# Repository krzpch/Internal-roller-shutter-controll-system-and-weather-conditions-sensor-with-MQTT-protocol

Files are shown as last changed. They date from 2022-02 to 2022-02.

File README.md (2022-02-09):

# Internal-roller-shutter-controll-system-and-weather-conditions-sensor-with-MQTT-protocol

This project is a part of smart home system based on MQTT protocol for comunication.
Weather condtions sensor is battery operated. To comunicate with shutter controll it uses Bluetooth Low Energy.
Shutter controll comunicates by Wi-Fi with MQTT Broker. It also works as a gate between Broker and Weather conditions sensor.

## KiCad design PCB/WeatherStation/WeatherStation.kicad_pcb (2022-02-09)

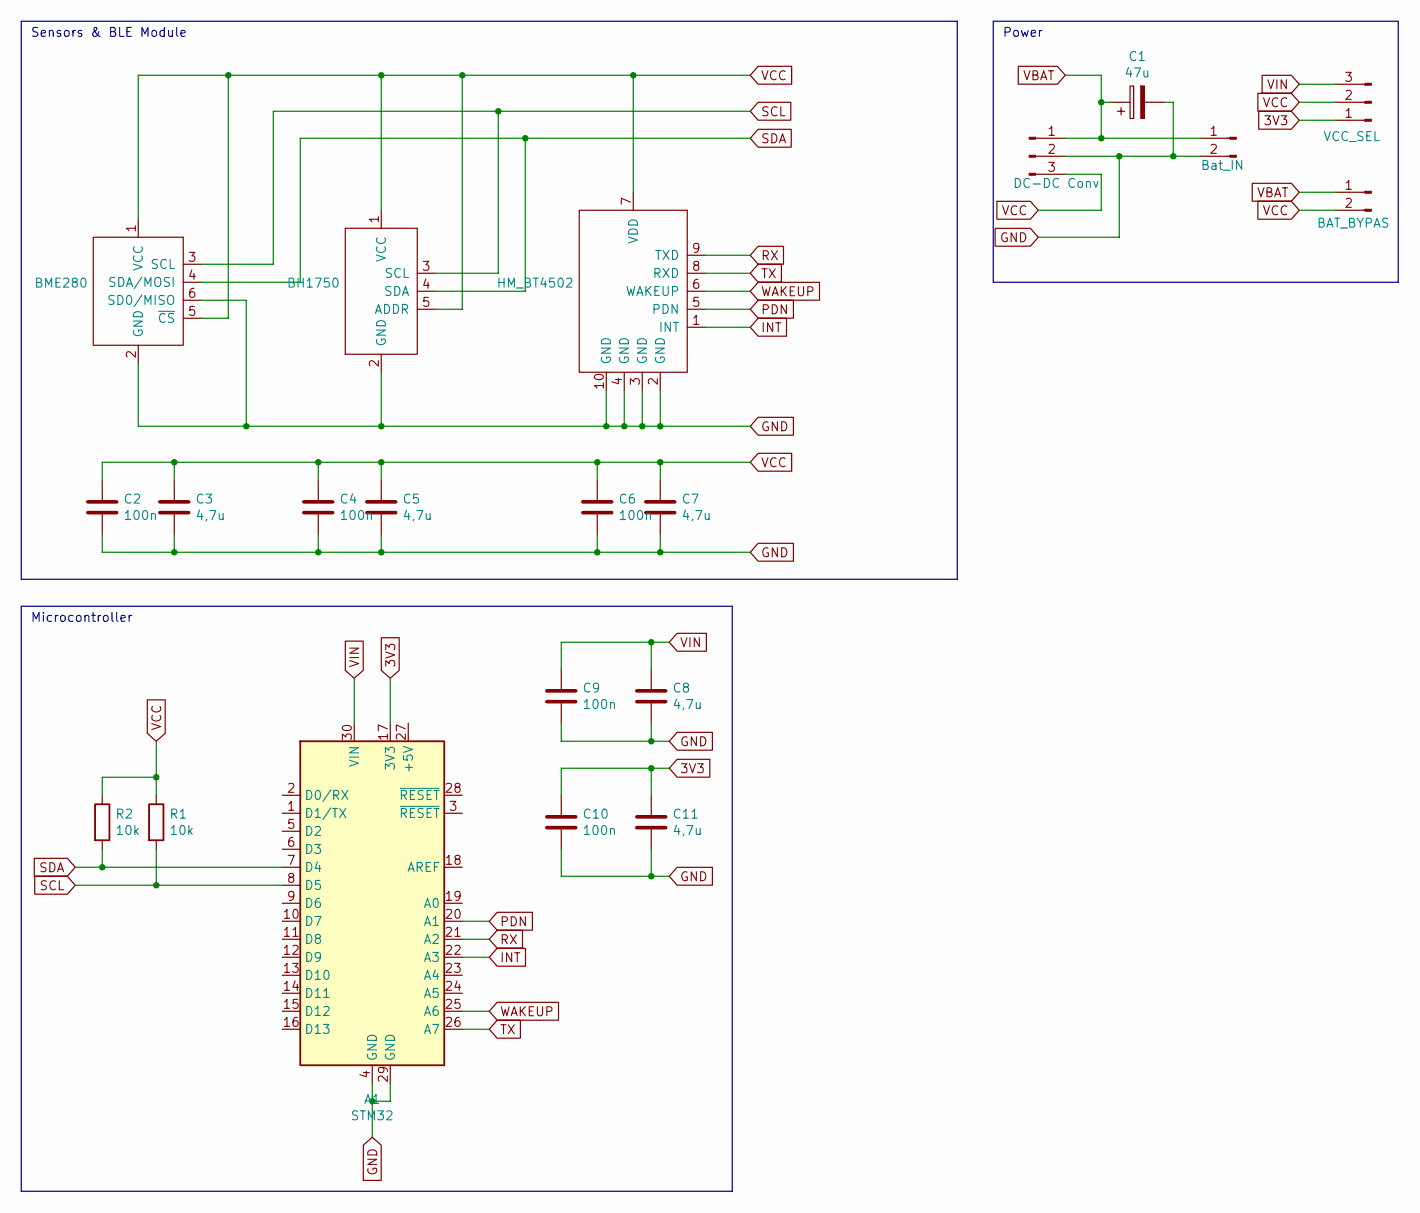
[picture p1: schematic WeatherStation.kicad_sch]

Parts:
A1: STM32; Arduino_Nano
BH1750: BH1750; PinHeader_1x05_P2.54mm_Vertical
BME280: BME280; PinHeader_1x06_P2.54mm_Vertical
C1: 47u; CP_Radial_D5.0mm_P2.00mm
C2, C4, C6, C9, C10: 100n; C_1206_3216Metric_Pad1.33x1.80mm_HandSolder
C3, C5, C7, C8, C11: 4,7u; C_1206_3216Metric_Pad1.33x1.80mm_HandSolder
HM_BT4502: HM_BT4502; HM-BT4502
J1: BAT_BYPAS; PinHeader_1x02_P2.54mm_Vertical
J2: VCC_SEL; PinHeader_1x03_P2.54mm_Vertical
J3: DC-DC Conv; PinHeader_1x03_P2.54mm_Vertical
J4: Bat_IN; PinHeader_1x02_P2.54mm_Vertical
R1, R2: 10k; R_Axial_DIN0207_L6.3mm_D2.5mm_P7.62mm_Horizontal

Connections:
3V3: A1.17 (3V3), C10.1, C11.1, J2.1
GND: A1.4 (GND), A1.29 (GND), BH1750.2 (GND), BME280.2 (GND), BME280.6 (SD0/MISO), C1.2, C2.2, C3.2, C4.2, C5.2, C6.2, C7.2, C8.2, C9.2, C10.2, C11.2, HM_BT4502.2 (GND), HM_BT4502.3 (GND), HM_BT4502.4 (GND), HM_BT4502.10 (GND), J3.2, J4.2
INT: A1.22 (A3), HM_BT4502.1 (INT)
PDN: A1.20 (A1), HM_BT4502.5 (PDN)
RX: A1.21 (A2), HM_BT4502.9 (TXD)
SCL: A1.8 (D5), BH1750.3 (SCL), BME280.3 (SCL), R1.2
SDA: A1.7 (D4), BH1750.4 (SDA), BME280.4 (SDA/MOSI), R2.2
TX: A1.26 (A7), HM_BT4502.8 (RXD)
VBAT: C1.1, J1.1, J3.1, J4.1
VCC: BH1750.1 (VCC), BH1750.5 (ADDR), BME280.1 (VCC), BME280.5 (~CS), C2.1, C3.1, C4.1, C5.1, C6.1, C7.1, HM_BT4502.7 (VDD), J1.2, J2.2, J3.3, R1.1, R2.1
VIN: A1.30 (VIN), C8.1, C9.1, J2.3
WAKEUP: A1.25 (A6), HM_BT4502.6 (WAKEUP)

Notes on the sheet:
Power
Microcontroller
Sensors & BLE Module

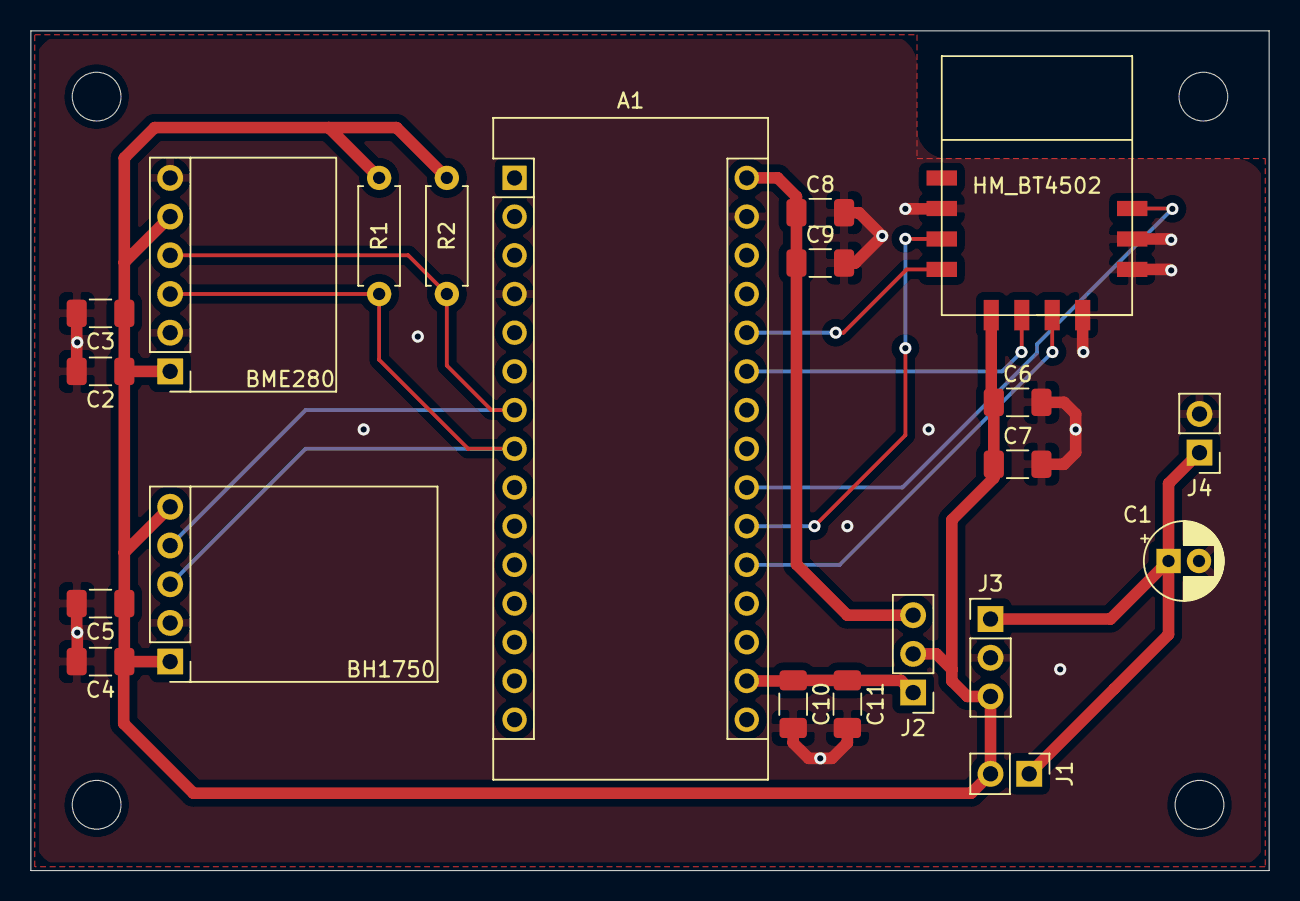
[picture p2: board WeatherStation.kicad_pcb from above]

Board: 2 copper layers, 81.3 x 55.1 mm, 21 parts (0 on the bottom side), 12 nets.

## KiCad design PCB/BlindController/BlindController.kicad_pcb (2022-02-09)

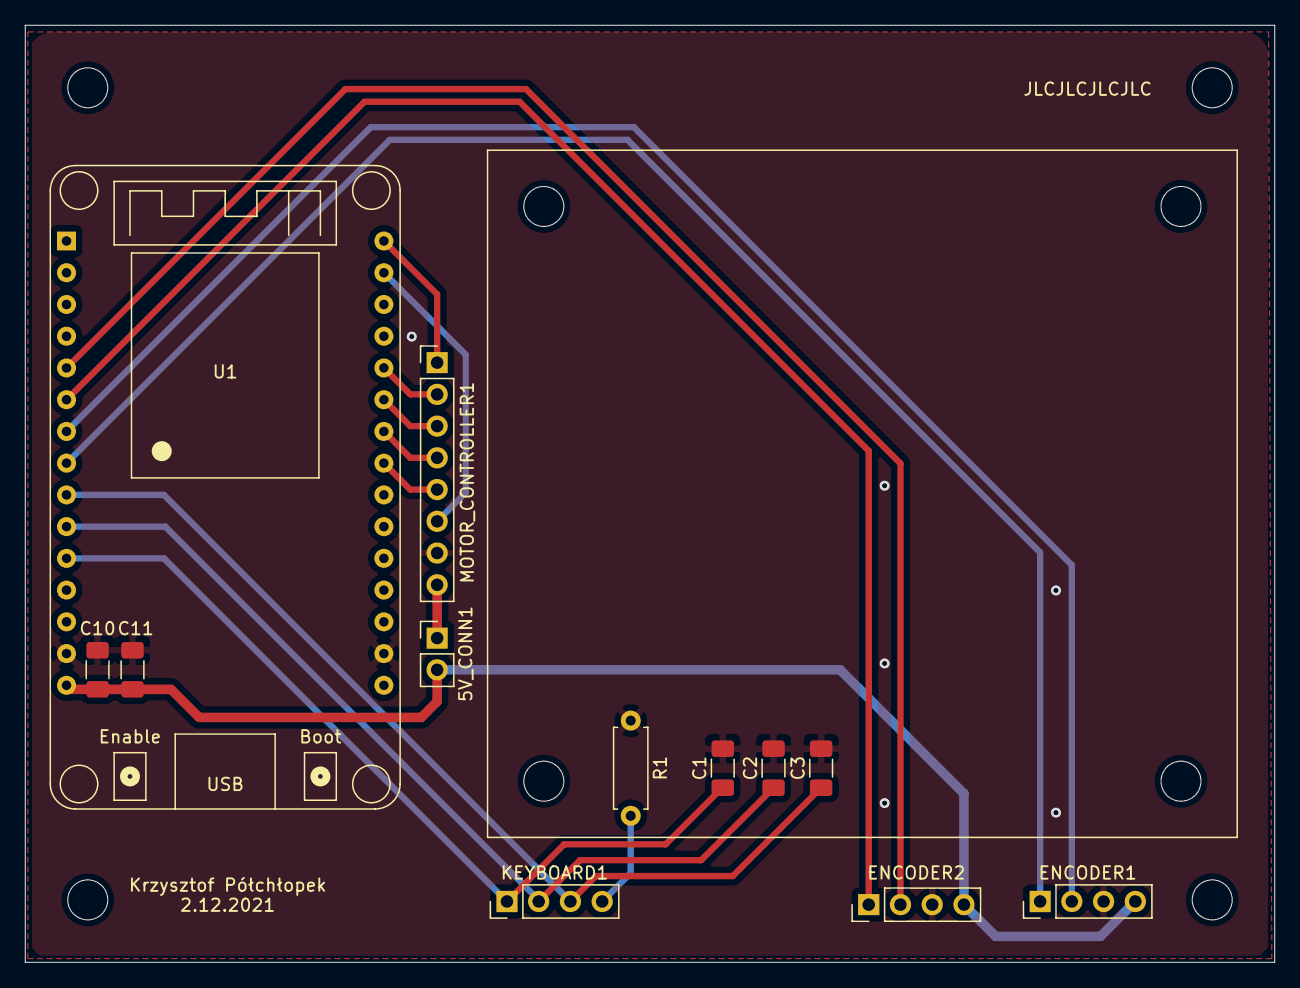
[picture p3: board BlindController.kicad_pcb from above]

Board: 2 copper layers, 100.0 x 75.0 mm, 12 parts (0 on the bottom side), 17 nets.

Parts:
5V_CONN1: 5V_CONN; PinHeader_1x02_P2.54mm_Vertical
C1, C2, C3, C10: 100n; C_1206_3216Metric_Pad1.33x1.80mm_HandSolder
C11: 4,7u; C_1206_3216Metric_Pad1.33x1.80mm_HandSolder
ENCODER1, ENCODER2: Conn_01x04_Male; PinHeader_1x04_P2.54mm_Vertical
KEYBOARD1: Conn_01x04_Male; PinHeader_1x04_P2.54mm_Vertical
MOTOR_CONTROLLER1: Conn_01x08_Male; PinHeader_1x08_P2.54mm_Vertical
R1: 10k; R_Axial_DIN0207_L6.3mm_D2.5mm_P7.62mm_Horizontal
U1: ESP32_DevKit_V1_DOIT; esp32_devkit_v1_doit

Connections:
5V: 5V_CONN1.2, C10.1, C11.1, ENCODER1.4, ENCODER2.4, U1.15
A_ENC1: ENCODER1.1, U1.8
A_ENC2: ENCODER1.2, U1.7
A_IN1: MOTOR_CONTROLLER1.2, U1.26
A_IN2: MOTOR_CONTROLLER1.3, U1.25
A_PWM: MOTOR_CONTROLLER1.1, U1.30
BUT1: C1.1, KEYBOARD1.1, U1.11
BUT2: C2.1, KEYBOARD1.2, U1.10
BUT3: C3.1, KEYBOARD1.3, U1.9
B_ENC1: ENCODER2.1, U1.6
B_ENC2: ENCODER2.2, U1.5
B_IN1: MOTOR_CONTROLLER1.4, U1.24
B_IN2: MOTOR_CONTROLLER1.5, U1.23
B_PWM: MOTOR_CONTROLLER1.6, U1.29
GND: C1.2, C2.2, C3.2, C10.2, C11.2, ENCODER1.3, ENCODER2.3, MOTOR_CONTROLLER1.7, R1.1, U1.14, U1.17
unnamed: 5V_CONN1.1, MOTOR_CONTROLLER1.8
unnamed: KEYBOARD1.4, R1.2

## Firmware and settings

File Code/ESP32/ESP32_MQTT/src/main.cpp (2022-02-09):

#include "EspMQTTClient.h"
#include "BLEDevice.h"
#include <sstream>

// Watchdog timer
#include <esp_task_wdt.h>
#define WDT_TIMEOUT 5

// EEPROM
#include <EEPROM.h>
//#define EEPROM	// if uncommented EEPROM STORAGE IS USED
#define EEPROM_SIZE 4 // 1 float 

// libs for motor controll
#include <motor.h>
#include <ESP32Encoder.h>

bool shutter_move = false;

int shutter_state = 0;

int64_t shutter_real_pos = 0;
int64_t shutter_up_pos = 0;
int64_t shutter_down_pos = 20000;

float mqtt_pos = 0;
float real_pos = shutter_real_pos / (shutter_down_pos - shutter_up_pos);

ESP32Encoder motorEncoder;

// keyboard
#define KEYBOARD_BUT1 14
#define KEYBOARD_BUT2 27
#define KEYBOARD_BUT3 26 //reserved

bool keyboard_overvrite = false;

// MQTT
EspMQTTClient client(
	"WIFI_SSID",	 	// SSID
	"WIFI_PASSWORD", 	// PASSWORD
	"192.168.137.89",	// MQTT Broker server ip
	"ESP32",		 	// Can be omitted if not needed
	"password",		 	// Can be omitted if not needed
	"ESP32",		 	// Client name that uniquely identify your device
	1883			 	// The MQTT port
);

// The remote service we wish to connect to.
static BLEUUID serviceUUID("0000ffe0-0000-1000-8000-00805f9b34fb");
// The characteristic of the remote service we are interested in.
static BLEUUID charUUID("0000ffe4-0000-1000-8000-00805f9b34fb");
//static BLEUUID char2UUID("0000ffe9-0000-1000-8000-00805f9b34fb");
static boolean doConnect = false;
static boolean connected = false;
static boolean doScan = false;
static BLERemoteCharacteristic *pRemoteCharacteristic;
static BLEAdvertisedDevice *myDevice;
static void notifyCallback(
	BLERemoteCharacteristic *pBLERemoteCharacteristic,
	uint8_t *pData, size_t length, bool isNotify)
{
	/*
Serial.print("Notify callback for characteristic ");
Serial.print(pBLERemoteCharacteristic->getUUID().toString().c_str());
Serial.print(" of data length ");
Serial.println(length);
Serial.print("data: ");
Serial.println((char *)pData);
*/
	String str;
	if (length >= 16 && client.isConnected())
	{
		float temp = *(float *)pData;
		float hum = *(float *)(pData + 4);
		float pres = *(float *)(pData + 8);
		float lx = *(float *)(pData + 12);
		str = "Temperature: " + String(temp) + " Humidity: " + String(hum) +
			  " Presurre: " + String(pres) + " Illuminance: " + String(lx);
		Serial.println(str);
		client.publish("Temperature", String(temp));
		client.publish("Humidity", String(hum));
		client.publish("Pressure", String(pres));
		client.publish("Illuminance", String(lx));
	}
}

class MyClientCallback : public BLEClientCallbacks
{
	void onConnect(BLEClient *pclient)
	{

	}
	void onDisconnect(BLEClient *pclient)
	{
		connected = false;
		Serial.println("onDisconnect");
		doScan = true;
	}
};

bool connectToServer()
{
	Serial.print("Forming a connection to ");
	Serial.println(myDevice->getAddress().toString().c_str());
	BLEClient *pClient = BLEDevice::createClient();
	Serial.println(" - Created client");
	pClient->setClientCallbacks(new MyClientCallback());
	// Connect to the remove BLE Server.
	pClient->connect(myDevice); // if you pass BLEAdvertisedDevice instead of address, it will be recognized type of peer device address (public or private)
	Serial.println(" - Connected to server");
	// Obtain a reference to the service we are after in the remote BLE server.
	BLERemoteService *pRemoteService = pClient->getService(serviceUUID);
	if (pRemoteService == nullptr)
	{
		Serial.print("Failed to find our service UUID: ");
		Serial.println(serviceUUID.toString().c_str());
		pClient->disconnect();
		return false;
	}
	Serial.println(" - Found our service");
	// Obtain a reference to the characteristic in the service of the remote BLE server.
	pRemoteCharacteristic = pRemoteService->getCharacteristic(charUUID);
	if (pRemoteCharacteristic == nullptr)
	{
		Serial.print("Failed to find our characteristic UUID: ");
		Serial.println(charUUID.toString().c_str());
		pClient->disconnect();
		return false;
	}
	Serial.println(" - Found our characteristic");
	// Read the value of the characteristic.
	if (pRemoteCharacteristic->canRead())
	{
		std::string value = pRemoteCharacteristic->readValue();
		Serial.print("The characteristic value was: ");
		Serial.println(value.c_str());
	}
	if (pRemoteCharacteristic->canNotify())
		pRemoteCharacteristic->registerForNotify(notifyCallback);
	connected = true;
	return true;
}

/**
 * Scan for BLE servers and find the first one that advertises the service we are looking for.
 */
class MyAdvertisedDeviceCallbacks : public BLEAdvertisedDeviceCallbacks
{
	/**
 * Called for each advertising BLE server.
 */
	void onResult(BLEAdvertisedDevice advertisedDevice)
	{
		// We have found a device, let us now see if it contains the service we are looking for.
		if (advertisedDevice.getAddress().toString() == "62:00:a1:1e:88:21")
		{
			BLEDevice::getScan()->stop();
			Serial.print("BLE Advertised Device found: ");
			Serial.println(advertisedDevice.toString().c_str());
			myDevice = new BLEAdvertisedDevice(advertisedDevice);
			doConnect = true;
			doScan = false;
		} // Found our server
	}	  // onResult

	
};		  // MyAdvertisedDeviceCallbacks

void setup()
{
	Serial.begin(115200);

	// motor controll
	motorEncoder.attachFullQuad(25, 33);
	motorEncoder.clearCount();

#ifdef EEPROM
	EEPROM.begin(EEPROM_SIZE);
	real_pos = EEPROM.readFloat(0);

	if (real_pos < 0.0f || real_pos > 1.0f ) { // check value
		real_pos = 0.0f;
	}
#endif 

	A_motor_init();

	

	shutter_move = false;
	A_soft_stop();

	// keyboard controll
	pinMode(KEYBOARD_BUT1, INPUT_PULLUP);
	pinMode(KEYBOARD_BUT2, INPUT_PULLUP);

	// Optionnal functionnalities of EspMQTTClient :
	client.enableDebuggingMessages();										   // Enable debugging messages sent to serial output
	client.enableHTTPWebUpdater();											   // Enable the web updater. User and password default to values of MQTTUsername and MQTTPassword. These can be overrited with enableHTTPWebUpdater("user", "password").
	client.enableLastWillMessage("TestClient/lastwill", "I am going offline"); // You can activate the retain flag by setting the third parameter to true


	BLEDevice::init("");
	BLEScan *pBLEScan = BLEDevice::getScan();
	pBLEScan->setAdvertisedDeviceCallbacks(new MyAdvertisedDeviceCallbacks());
	pBLEScan->setInterval(1349);
	pBLEScan->setWindow(449);
	pBLEScan->setActiveScan(false);
	doScan = true;
	//pBLEScan->start(5, false);

	// Watchdog timer setup
	esp_task_wdt_init(WDT_TIMEOUT, true);
	esp_task_wdt_add(NULL);
}

// This function is called once everything is connected (Wifi and MQTT)
// WARNING : YOU MUST IMPLEMENT IT IF YOU USE EspMQTTClient
void onConnectionEstablished()
{
	client.isConnected();
	client.subscribe("Shutter_com", [](const String &payload)
					{
						Serial.println("Shutter command:" + String(shutter_state));
						if (payload == "STOP")
						{
							Serial.println("Stoping");
							shutter_state = (int)((shutter_real_pos / ((float)(shutter_down_pos - shutter_up_pos))) * 100);
							mqtt_pos = (float)shutter_state / 100;
						}
						else
						{
							shutter_state = payload.toInt();
							mqtt_pos = (float)shutter_state / 100;
						}
					});
#ifdef EEPROM
	real_pos = EEPROM.readFloat(0);
	shutter_state = (int)((real_pos) * 100);
	client.publish("Shutter", String(shutter_state));
#endif
}

void loop()
{
	// Watchdog timer reset
	esp_task_wdt_reset();

	// EEPROM
#ifdef EEPROM
	if (EEPROM.readFloat(0) != real_pos)
	EEPROM.writeFloat(0,real_pos);
	EEPROM.commit();
#endif 

	client.loop();

	// motor controll
	shutter_real_pos = motorEncoder.getCount();
	real_pos = shutter_real_pos / ((float)(shutter_down_pos - shutter_up_pos));
	
	if (client.isConnected()) {
		if (mqtt_pos > (real_pos + 0.005f))
		{
			shutter_move = true;
			A_turn_counterclockwise(100);
			shutter_state = (int)((real_pos) * 100);
			client.publish("Shutter", String(shutter_state));
			Serial.println("Moving DOWN");
		}
		else if (mqtt_pos < (real_pos - 0.005f))
		{
			shutter_move = true;
			A_turn_clockwise(100);
			shutter_state = (int)((real_pos) * 100);
			client.publish("Shutter", String(shutter_state));
			Serial.println("Moving UP");
			//Serial.println("Status:" + String(real_pos, 4));
		}
		else
		{
			shutter_move = false;
			A_soft_stop();
		}
	}
		

	// keyboard support
	if (digitalRead(KEYBOARD_BUT1) == LOW)
	{
		Serial.println("KEYBOARD_UP");
		keyboard_overvrite = true;
		A_turn_clockwise(100);
		//A_turn_counterclockwise(100);
		while (digitalRead(KEYBOARD_BUT1) == LOW)
		{
			shutter_real_pos = motorEncoder.getCount();
			real_pos = shutter_real_pos / ((float)(shutter_down_pos - shutter_up_pos));			
			shutter_state = (int)(real_pos * 100);
			mqtt_pos = real_pos;
			if (client.isConnected()) {
				client.publish("Shutter", String(shutter_state));
			}
			
			if (real_pos < 0.01f)
			{ //shutter_state < 0.05f
				Serial.println("STOP_UP");
				A_soft_stop();
			}
			delay(10);
			esp_task_wdt_reset();
		}
	}
	if (digitalRead(KEYBOARD_BUT2) == LOW)
	{
		Serial.println("KEYBOARD_DOWN");
		keyboard_overvrite = true;
		//A_turn_clockwise(100);
		A_turn_counterclockwise(100);
		while (digitalRead(KEYBOARD_BUT2) == LOW)
		{
			shutter_real_pos = motorEncoder.getCount();
			real_pos = shutter_real_pos / ((float)(shutter_down_pos - shutter_up_pos));
			shutter_state = (int)(real_pos * 100);
			mqtt_pos = real_pos;
			if (client.isConnected()) {
				client.publish("Shutter", String(shutter_state));
			}
			if (real_pos >= 0.995f)
			{ //shutter_state >= 0.95f
				Serial.println("STOP_DOWN");
				A_soft_stop();
			}
			delay(10);
			esp_task_wdt_reset();
		}
	}
	if (keyboard_overvrite == true)
	{
		keyboard_overvrite = false;
		A_soft_stop();
		delay(10);
		
	}

	if (doConnect == true)
	{
		if (connectToServer())
		{
			Serial.println("We are now connected to the BLE Server.");
		}
		else
		{
			Serial.println("We have failed to connect to the server; there is nothin more we will do.");
		}
		doConnect = false;
	}
	// If we are connected to a peer BLE Server, update the characteristic each time we are reached
	// with the current time since boot.
	if (connected)
	{
		// if connection was established

	}
	else if (doScan && !shutter_move) // check if shutter is moving
	{
		if (client.isConnected()) {
			Serial.println("Scaning");
			BLEDevice::getScan()->start(1); // this is just example to start scan after disconnect, most likely there is better way to do it in arduino
		}
	}
	delay(100);



}

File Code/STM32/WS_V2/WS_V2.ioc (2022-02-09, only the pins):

Mcu.UserName=STM32L432KCUx
PA0.GPIO_Label=MCO [High speed clock in]
PA0.Signal=RCC_CK_IN
PA1.GPIO_Label=BT_PDN
PA1.Signal=GPIO_Output
PA2.Signal=LPUART1_TX
PA3.Signal=LPUART1_RX
PA4.GPIO_Label=BT_INT
PA4.Signal=GPXTI4
PA7.GPIO_Label=BT_WAKEUP
PA7.Signal=GPIO_Output
PB6.Signal=I2C1_SCL
PB7.Signal=I2C1_SDA

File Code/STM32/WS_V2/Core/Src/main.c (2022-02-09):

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
/* Includes ------------------------------------------------------------------*/
#include "main.h"
#include "i2c.h"
#include "usart.h"
#include "rtc.h"
#include "gpio.h"

/* USER CODE BEGIN Includes */
#include <string.h>
#include <stdio.h>
#include "bh1750.h"
#include "bme280.h"
#include "hm-bt4502.h"
/* USER CODE END Includes */

/* USER CODE BEGIN PD */
#define BLE_RxTableLen 20
#define BLE_TxTableLen 50
/* USER CODE END PD */


/* USER CODE BEGIN PV */
// RTC variables
uint8_t RTC_interrupt = 0;

// BLE variables
uint8_t BLE_interrupt = 0;
uint16_t BLE_RxLen;
uint8_t BLE_RxTable[BLE_RxTableLen];
uint16_t BLE_TxLen;
uint8_t BLE_TxTable[BLE_TxTableLen];
uint8_t BLE_connected = 0;

// sensor variables
bme280_t bme;
bh1750_t bh;
/* USER CODE END PV */

void SystemClock_Config(void);
/* USER CODE BEGIN PFP */
void LED_Blink(uint8_t blinsk,uint16_t interval);
/* USER CODE END PFP */

/**
  * @brief  The application entry point.
  * @retval int
  */
int main(void)
{
  /* MCU Configuration--------------------------------------------------------*/

  /* Reset of all peripherals, Initializes the Flash interface and the Systick. */
  HAL_Init();

  /* Configure the system clock */
  SystemClock_Config();

  /* Initialize all configured peripherals */
  MX_GPIO_Init();
  MX_I2C1_Init();
  MX_LPUART1_UART_Init();
  MX_RTC_Init();
  /* USER CODE BEGIN 2 */

	bme.i2c = &hi2c1;

	bme.filter = BME280_FILTER_OFF;
	bme.temp_oversampling = BME280_TEMPERATURE_OVER_1;
	bme.press_oversampling = BME280_PRESSURE_OVER_1;
	bme.hum_oversampling = BME280_HUMIDITY_OVER_1;
	bme.work_mode = BME280_NORMAL_MODE;
	bme.standby_time = BME280_STANDBY_20;

	bh.i2c = &hi2c1;
	bh.work_mode = BH1750_ONE_H_RES2_MODE;

	BME280_Init(&bme);
	bh1750_init(&bh);

	btInit();	// initialize ble pins and reset module
	memset((void*) BLE_RxTable, '\0', sizeof(BLE_RxTable));

	LED_Blink(1, 400);

	BME280_ReadAll(&bme);
	bh1750_ReadMeasurement(&bh);

	LED_Blink(1, 400);

	HAL_RTCEx_SetWakeUpTimer_IT(&hrtc, 10, RTC_WAKEUPCLOCK_CK_SPRE_16BITS);

  /* USER CODE END 2 */

  /* Infinite loop */
  /* USER CODE BEGIN WHILE */
	while (1) {


		if (BLE_interrupt == 1) {
			BLE_interrupt = 0;
			if (strcmp((char*) BLE_RxTable, (char*) "TTM:CONNECT\r\n") == 0) {
				BLE_connected = 1;
				LED_Blink(3, 200);
				if (BLE_connected == 1) {
					BME280_ReadAll(&bme);
					bh1750_ReadMeasurement(&bh);

					memcpy((uint8_t*)BLE_TxTable, &bme.temp, 4);
					memcpy((uint8_t*)BLE_TxTable + 4, &bme.hum, 4);
					memcpy((uint8_t*)BLE_TxTable + 8, &bme.press, 4);
					memcpy((uint8_t*)BLE_TxTable + 12, &bh.lx, 4);

					//BLE_TxLen = sprintf((char*) BLE_TxTable, "T:%.2f H:%.2f P:%.2f L:%.2f\n", bme.temp, bme.hum, bme.press, bh.lx);
					HAL_Delay(1000);
					// send and go to sleep

					btSend((uint8_t*) BLE_TxTable, 16);
					memset((void*) BLE_TxTable, 0, sizeof(BLE_TxTable));
					HAL_Delay(1000);
					btSleep();

					BLE_connected = 0;
				}

				HAL_RTCEx_SetWakeUpTimer_IT(&hrtc, 60, RTC_WAKEUPCLOCK_CK_SPRE_16BITS);

			} else if (strcmp((char*) BLE_RxTable, (char*) "TTM:DISCONNECT\r\n") == 0) {
				BLE_connected = 0;
				LED_Blink(2, 200);
			} else if (strcmp((char*) BLE_RxTable, (char*) "TTM:DISCONNECT FOR TIMEOUT\r\n") == 0) {
				LED_Blink(1, 500);
				NVIC_SystemReset();

			}
			memset((void*) BLE_RxTable, 0, sizeof(BLE_RxTable));
		}

		if (RTC_interrupt == 1) {
			RTC_interrupt = 0;

			if (btGetState() == GPIO_PIN_SET) {
				// if BT module is in sleep wake it up and set timer for 10 seconds
				btWakeup();
				HAL_RTCEx_SetWakeUpTimer_IT(&hrtc, 10, RTC_WAKEUPCLOCK_CK_SPRE_16BITS);

			} else {
				//else wait for 1 min for next connection cycle
				BLE_connected = 0;
				btSleep();
				HAL_RTCEx_SetWakeUpTimer_IT(&hrtc, 60, RTC_WAKEUPCLOCK_CK_SPRE_16BITS);
			}

		}
		//HAL_GPIO_TogglePin(LD3_GPIO_Port, LD3_Pin);
    /* USER CODE END WHILE */

    /* USER CODE BEGIN 3 */

		HAL_SuspendTick();
		HAL_PWREx_EnterSTOP2Mode(PWR_STOPENTRY_WFI);
	}
  /* USER CODE END 3 */
}

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
/* USER CODE BEGIN 4 */
void HAL_RTCEx_WakeUpTimerEventCallback(RTC_HandleTypeDef *hrtc) {
	SystemClock_Config();
	HAL_ResumeTick();
	HAL_RTCEx_DeactivateWakeUpTimer(hrtc);
	RTC_interrupt = 1;
}

void HAL_GPIO_EXTI_Callback(uint16_t GPIO_Pin) {
	SystemClock_Config();
	HAL_ResumeTick();
	if (GPIO_Pin == BT_INT_Pin) {
		HAL_UARTEx_ReceiveToIdle(&hlpuart1, (uint8_t*) BLE_RxTable,
				BLE_RxTableLen, &BLE_RxLen, 30);
		if (BLE_RxLen > 0) { // set flag only if received something
			BLE_interrupt = 1;
		}
	}
}

void LED_Blink(uint8_t blinsk,uint16_t interval) {
	for (uint8_t i = 0; i < blinsk; i++) {
		HAL_GPIO_WritePin(LD3_GPIO_Port, LD3_Pin, GPIO_PIN_SET);
		HAL_Delay(interval>>1);
		HAL_GPIO_WritePin(LD3_GPIO_Port, LD3_Pin, GPIO_PIN_RESET);
		HAL_Delay(interval>>1);
	}

}

/* USER CODE END 4 */
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


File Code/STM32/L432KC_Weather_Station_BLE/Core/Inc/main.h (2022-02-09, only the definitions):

#define BT_PDN_Pin GPIO_PIN_1
#define BT_PDN_GPIO_Port GPIOA
#define BT_INT_Pin GPIO_PIN_4
#define BT_INT_GPIO_Port GPIOA
#define BT_INT_EXTI_IRQn EXTI4_IRQn
#define BT_WAKEUP_Pin GPIO_PIN_7
#define BT_WAKEUP_GPIO_Port GPIOA
#define SWDIO_Pin GPIO_PIN_13
#define SWDIO_GPIO_Port GPIOA
#define SWCLK_Pin GPIO_PIN_14
#define SWCLK_GPIO_Port GPIOA
#define LD3_Pin GPIO_PIN_3
#define LD3_GPIO_Port GPIOB

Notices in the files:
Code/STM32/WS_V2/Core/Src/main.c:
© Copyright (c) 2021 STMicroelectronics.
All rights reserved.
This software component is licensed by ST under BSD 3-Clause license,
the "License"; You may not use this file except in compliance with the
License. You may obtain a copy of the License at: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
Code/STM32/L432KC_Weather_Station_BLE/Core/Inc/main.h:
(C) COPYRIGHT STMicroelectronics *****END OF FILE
